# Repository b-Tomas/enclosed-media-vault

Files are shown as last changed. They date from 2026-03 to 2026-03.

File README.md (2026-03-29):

# 10" 2U Raspberry Pi 5 NAS with 6x 2.5" HDDs

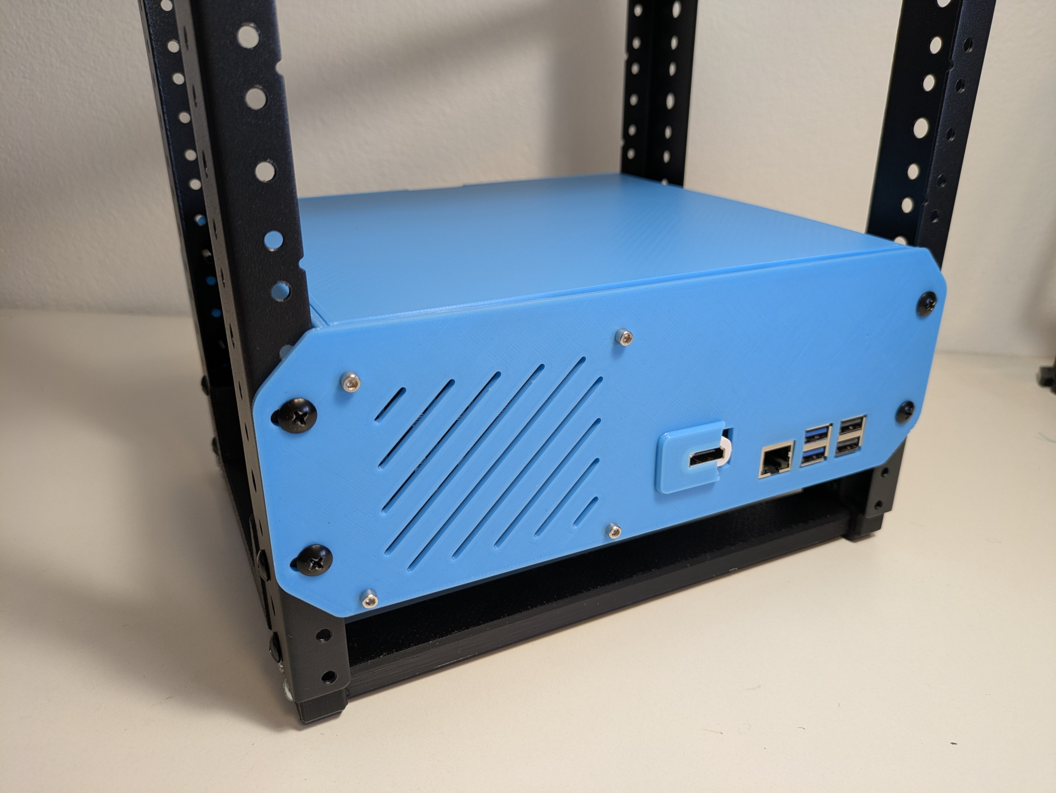
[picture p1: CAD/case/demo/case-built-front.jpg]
Assembled NAS in 10 inch rack


A 3D-printed 2U enclosure for a Raspberry Pi 5 NAS running OpenMediaVault, designed to fit a 10" mini rack. Fits up to 6x 2.5" SATA drives connected through a 6-port M.2-to-SATA adapter while booting from an NVMe SSD. Both M.2 devices run on a single PCIe lane via a switch HAT.

## Specs

| | |
| --- | --- |
| **Compute** | Raspberry Pi 5 8GB |
| **Boot drive** | 128GB M.2 2242 NVMe |
| **Storage** | 6x 1TB 2.5" SATA HDD (recycled from laptop SSD upgrades) |
| **PCIe HAT** | Geekworm X1004 dual M.2 HAT (ASM1182e PCIe switch) |
| **SATA adapter** | M.2 to SATA 6-port (ASM1166) |
| **Power** | 5V 15A PSU + SATA splitter cables |
| **OS** | OpenMediaVault |
| **Rack** | 3D-printed 10" mini rack with 6U steel rails |

## 3D-printed parts

| Component | Printables | Source |
| --- | --- | --- |
| Base chassis (2U, for 220x220mm bed) | [Printables](https://www.printables.com/model/1639121-10-2u-chassis-base-for-220x220mm-bed) | [`CAD/base-chassis/`](CAD/base-chassis/) |
| Drive box (6x 2.5") | [Printables](https://www.printables.com/model/1639132-6x-25-drive-box) | [`CAD/drives/`](CAD/drives/) |
| NAS case (2U enclosed) | <!-- TODO: upload to Printables --> | [`CAD/case/`](CAD/case/) |

All designs are FreeCAD projects with exported STLs. See [3D printing details](docs/3d-printing.md) for print notes, pending work, and third-party models used.

## Documentation

- [Bill of materials](docs/bom.md): full parts list with prices and links
- [Hardware alternatives](docs/hardware-alternatives.md): other hardware approaches explored (SATA HATs, USB, Compute Module)
- [Software](docs/software.md): OMV setup, boot fix for SATA controllers, other OSes tried
- [3D printing](docs/3d-printing.md): custom designs, STL inventory, third-party prints, reference models
- [References](docs/references.md): external links and resources

## License

[MIT](LICENSE)

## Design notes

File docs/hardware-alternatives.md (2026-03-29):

# Hardware alternatives

The Raspberry Pi 5 exposes a single PCIe 2.0 x1 lane. Connecting both an NVMe boot drive and multiple SATA storage drives from that one lane requires a PCIe switch as a workaround. This document covers the approaches considered and the one ultimately chosen.

## Chosen: Geekworm X1004 dual M.2 HAT

The final build uses the [Geekworm X1004](https://www.amazon.com/Geekworm-X1004-Peripheral-Board-Raspberry/dp/B0D3LP9KBH), a dual M.2 HAT that sits on top of the Pi 5. It has an ASM1182e PCIe switch on-board, splitting the single PCIe lane into two M.2 slots:

- **Slot 1:** 128GB 2242 NVMe SSD OEM drive bought from a shop selling scrap parts (boot drive)
- **Slot 2:** [M.2 to SATA 6-Port adapter](https://www.amazon.com/Adapter-RIITOP-Expansion-Chipset-ASM1166/dp/B0D8BCWHPT) (ASM1166 chipset) -> 6x SATA

Power is supplied by an [5V 15A PSU](https://www.amazon.com/dp/B078RT3ZPS) (I went for the biggest one, but I am not sure I would trust 15A on it), with [SATA splitter cables](https://www.amazon.com/dp/B0DFRJT3CW) distributing power to the drives (soldering required).

The original Raspberry Pi M.2 HAT (single slot, PCIe 2.0) was purchased earlier and used for a year or so when I was using a single drive on a USB adapter, but it not used in the final build.

### PCIe topology

```
$ lspci
0001:00:00.0 PCI bridge: Broadcom Inc. and subsidiaries BCM2712 PCIe Bridge (rev 21)
0001:01:00.0 PCI bridge: ASMedia Technology Inc. ASM1182e 2-Port PCIe x1 Gen2 Packet Switch
0001:02:03.0 PCI bridge: ASMedia Technology Inc. ASM1182e 2-Port PCIe x1 Gen2 Packet Switch
0001:02:07.0 PCI bridge: ASMedia Technology Inc. ASM1182e 2-Port PCIe x1 Gen2 Packet Switch
0001:03:00.0 Non-Volatile memory controller: Shenzhen Unionmemory Information System Ltd. AM620 PCIe 3.0 NVMe SSD 128GB (rev 03)
0001:04:00.0 SATA controller: ASMedia Technology Inc. ASM1166 Serial ATA Controller (rev 02)
0002:00:00.0 PCI bridge: Broadcom Inc. and subsidiaries BCM2712 PCIe Bridge (rev 21)
0002:01:00.0 Ethernet controller: Raspberry Pi Ltd RP1 PCIe 2.0 South Bridge
```

## Alternative A: FPC PCIe switch + dedicated SATA HAT

Use a separate FPC-based PCIe switch HAT to split the lane, then attach both the existing M.2 HAT and a dedicated SATA HAT.

| Component | Price | Link |
| --- | --- | --- |
| GeeekPi RPi5 B12 Dual FPC PCIe HAT | USD 24.99 | [Amazon](https://www.amazon.com/GeeekPi-HAT-Raspberry-B12-Interface/dp/B0D2VTL9G5) |
| Radxa Penta SATA HAT | USD 79.99 | [Amazon](https://www.amazon.com/Radxa-Penta-SATA-HAT-Raspberry/dp/B0DX1HQWB2) |
| Geekworm X1009 PCIe to 5-port SATA HAT | USD 60.00 | [AliExpress](https://es.aliexpress.com/item/1005009068994117.html) |
| Waveshare Pi5 Connector Adapter C | USD 10.00 | [Waveshare](https://www.waveshare.com/pi5-connector-adapter-c.htm) |

**Downsides:** The Penta SATA HAT is expensive and hard to source. The X1009 is more affordable and includes 12V DC input (also powers the Pi; do NOT also power via USB-C), but still requires the FPC switch HAT on top.

## Alternative B: Dual M.2 HAT + M.2-to-SATA adapter

This is the approach that was ultimately chosen (see above). For reference, cheaper alternatives were also considered:

| Component | Price | Link |
| --- | --- | --- |
| Geekworm X1004 Dual M.2 HAT (supports boot) | USD 29.90 | [Amazon](https://www.amazon.com/Geekworm-X1004-Peripheral-Board-Raspberry/dp/B0D3LP9KBH) |
| Cheaper dual M.2 HAT (likely no boot support) | USD 18.59 | [AliExpress](https://es.aliexpress.com/item/1005007485668597.html) |
| Another dual M.2 option | USD 25.99 | [AliExpress](https://es.aliexpress.com/item/1005006533152444.html) |
| RIITOP M.2 to SATA 6-Port (ASM1166) | USD 39.99 | [Amazon](https://www.amazon.com/Adapter-RIITOP-Expansion-Chipset-ASM1166/dp/B0D8BCWHPT)  |
| Cheaper M.2 to SATA adapter | -- | [AliExpress](https://es.aliexpress.com/item/1005010015675089.html) |

## Alternative C: USB 3.0 to SATA

The simplest approach. No PCIe splitting needed. Just plug USB-to-SATA adapters into the Pi's USB 3.0 ports.

| Component | Price | Link |
| --- | --- | --- |
| USB 3.0 to 2.5" SATA adapter | ARS 23,200 (x2) | [MercadoLibre](https://www.mercadolibre.com.ar/cable-sata-usb-30-adaptador-conversor-disco-hdd-ssd-25-color-negro/p/MLA48683516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) |

**Trade-off:** Simple and cheap, but bandwidth-limited by USB 3.0 and no hardware RAID support. Two adapters were purchased early on during experimentation. Originally used with a single WD Elements 2TB drive; considered buying more but moved to the PCIe SATA approach instead.

**Notes:**

- I tried connecting a couple of USB drives at once to move files around, and the controller evetually died
- OMV does not support creeating RAID or ZFS filesystems over USB drives. I experimented with a RAID1 setup with two 1TB drives that performed fine, but I had to create it via CLI.

## Alternative D: Compute Module 5

Use a CM5 with a carrier board that has native SATA ports and an NVMe slot, eliminating the need for PCIe switching entirely.

| Component | Price | Link |
| --- | --- | --- |
| Exaviz Interceptor Carrier Board v2.0 | ~USD 80 | [Exaviz](https://www.exaviz.com/product-page/interceptor-carrier-board-v2-0) |
| Radxa Taco IO Board | -- | [Radxa](https://radxa.com/products/io-board/taco/#techspec) |

**Blocker:** The CM5 is hard to obtain, and can get expensive.

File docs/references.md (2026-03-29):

# References

## Inspiration

- [Project Mini Rack](https://www.jeffgeerling.com/blog/2024/project-mini-rack-compact-and-portable-homelabs) -- Jeff Geerling's compact homelab project
- [geerlingguy/mini-rack](https://github.com/geerlingguy/mini-rack) -- GitHub repo with builds and documentation

## Pi 5 PCIe

- [Pi PCIe HAT database](https://pipci.jeffgeerling.com/hats) -- compatibility list for PCIe HATs
- [Testing PCIe on Raspberry Pi 5](https://www.jeffgeerling.com/blog/2023/testing-pcie-on-raspberry-pi-5)

## Troubleshooting

- [AHCI boot fix discussion](https://forums.raspberrypi.com/viewtopic.php?t=363682#p2195153) -- Raspberry Pi forums
- [raspberrypi/linux#4848](https://github.com/raspberrypi/linux/issues/4848) -- related kernel issue

## NixOS on Pi 5

- [NixOS Wiki: Raspberry Pi 5](https://wiki.nixos.org/wiki/NixOS_on_ARM/Raspberry_Pi_5)
- [pdg137/pi5-nixos-setup](https://github.com/pdg137/pi5-nixos-setup)
- [nvmd/nixos-raspberrypi](https://github.com/nvmd/nixos-raspberrypi)

## Compute Module research

- [ChatGPT deep research: CM5 carrier boards](https://chatgpt.com/share/68ed2ff8-9aa0-8009-b2a6-e3ce2d3727fe)
- [Exaviz Interceptor Carrier Board v2.0](https://www.exaviz.com/product-page/interceptor-carrier-board-v2-0)
- [Radxa Taco IO Board](https://radxa.com/products/io-board/taco/#techspec)

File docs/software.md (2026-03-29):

# Software

## Current setup: OpenMediaVault

The NAS runs [OpenMediaVault](https://www.openmediavault.org/) on a Raspberry Pi 5, booting from the NVMe SSD behind the Geekworm X1004's PCIe switch.

<!-- TODO: OMV version, share configuration, ZFS setup, apps -->

## SATA controller boot fix

With the ASM1166 SATA controller and hard drives connected, the Pi would crash at boot with:

```
AHCI controller unavailable!
```

The fix is included in recent kernels. Add to `/boot/firmware/config.txt`:

```ini
# Required for SATA controllers behind PCIe switches.
# See: https://github.com/raspberrypi/linux/issues/4848
#      https://forums.raspberrypi.com/viewtopic.php?t=363682#p2195153
dtoverlay=pciex1-compat-pi5,no-mip
dtoverlay=pcie-32bit-dma-pi5
```

## Other OSes explored

### Umbrel

Tried early on. Nice UI, but too limited for NAS use. Lacks proper storage management, RAID, and file sharing configuration.

### NixOS

No official support for RPi 5. I managed to install and boot it but did not invest too much time in setting it up. Built the image on a Pop!\_OS-based x86 VM with Nix installed.

Resources:

- [NixOS on ARM: Raspberry Pi 5](https://wiki.nixos.org/wiki/NixOS_on_ARM/Raspberry_Pi_5)
- [pdg137/pi5-nixos-setup](https://github.com/pdg137/pi5-nixos-setup) (deployment example)
- [nvmd/nixos-raspberrypi](https://github.com/nvmd/nixos-raspberrypi) (upstream reference)

<!-- TODO: NixOS configuration details if/when completed -->

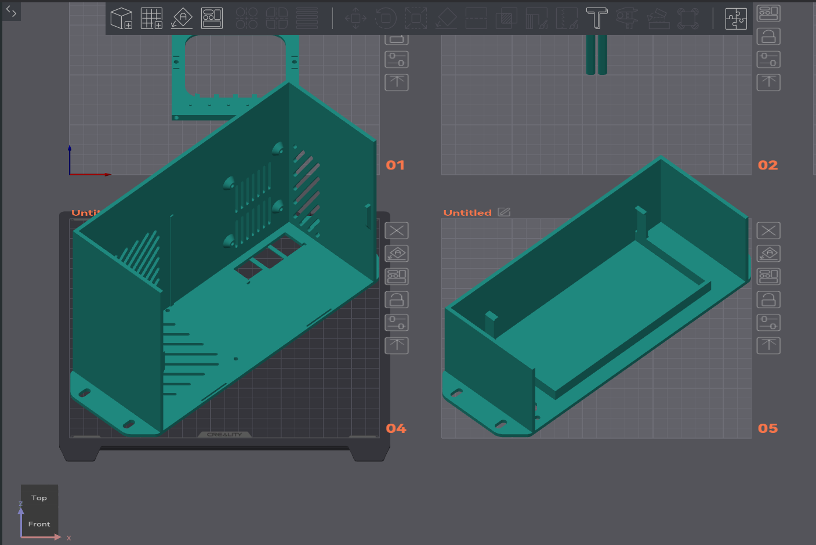
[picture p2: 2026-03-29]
CAD/base-chassis/demo/base-examples-slicer.png

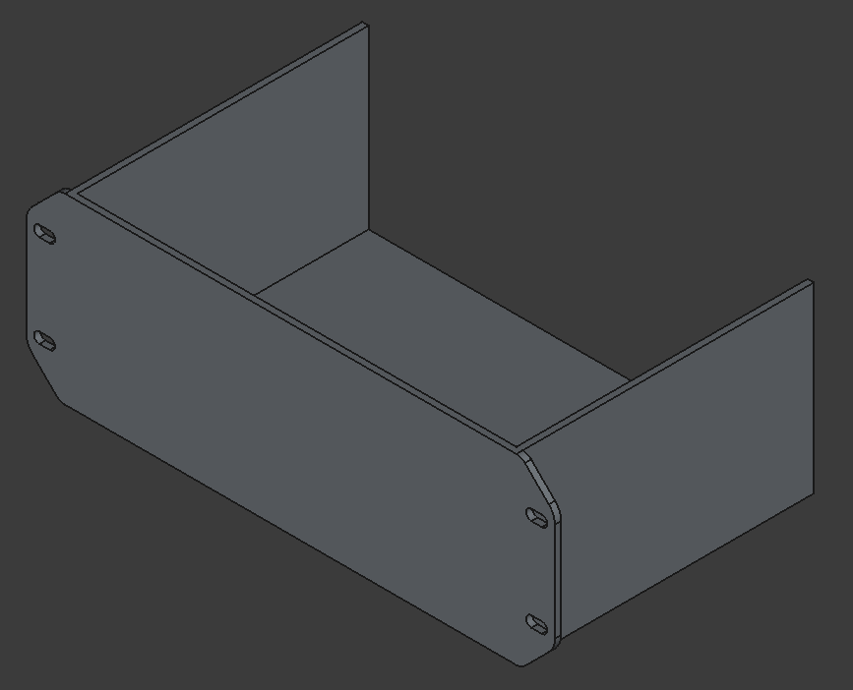
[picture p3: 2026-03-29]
CAD/base-chassis/demo/base-freecad.png

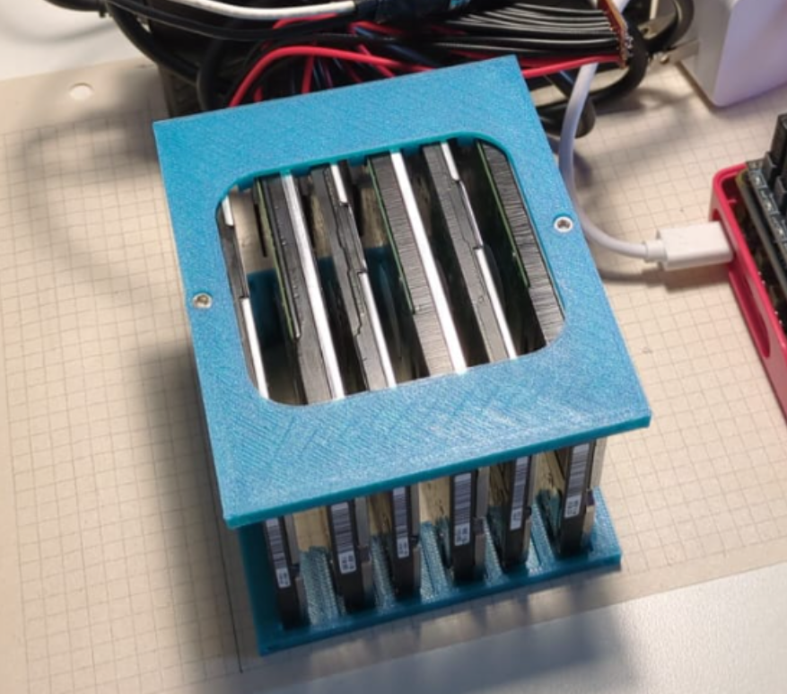
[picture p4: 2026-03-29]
CAD/drives/demo/drives-built.png

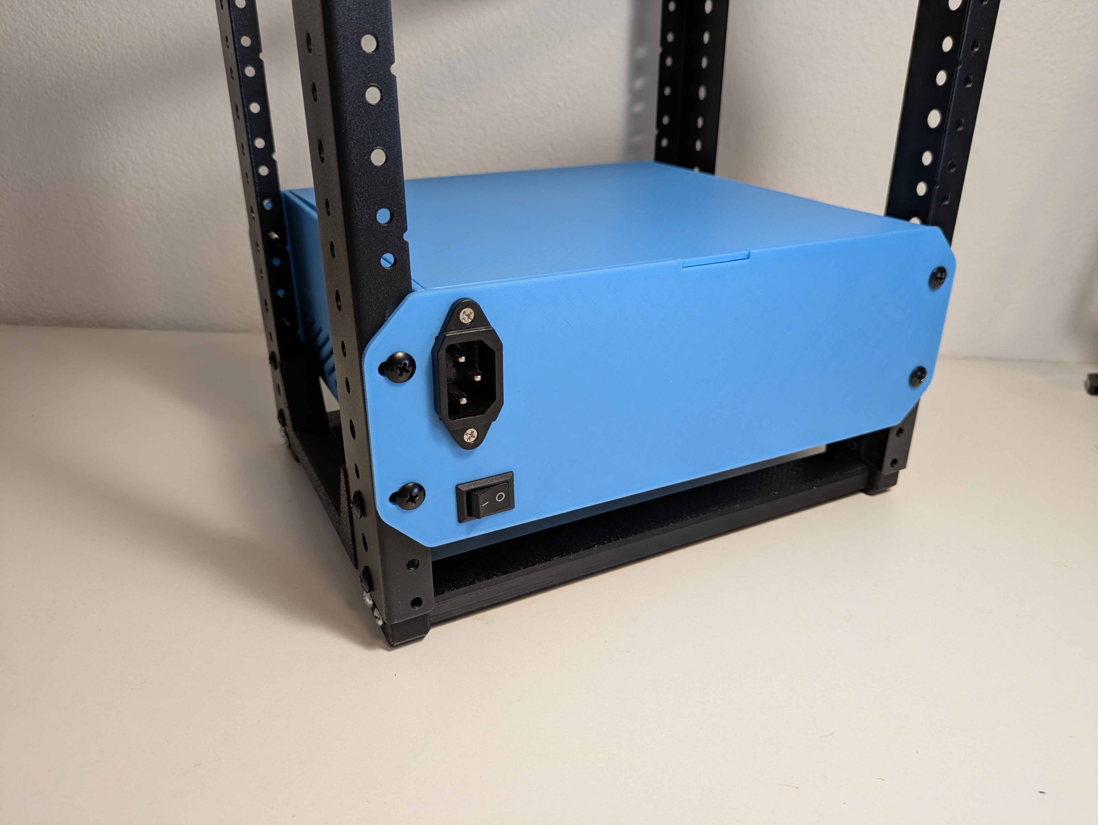
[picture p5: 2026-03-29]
CAD/case/demo/case-built-back.jpg

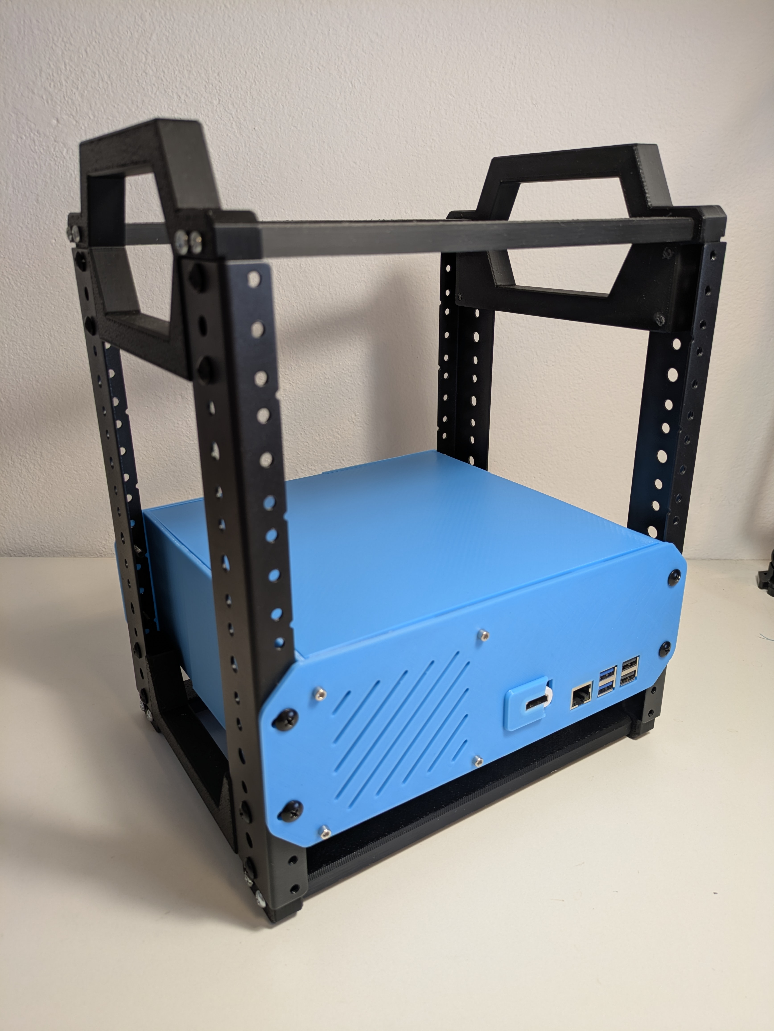
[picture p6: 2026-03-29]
CAD/case/demo/rack.jpg

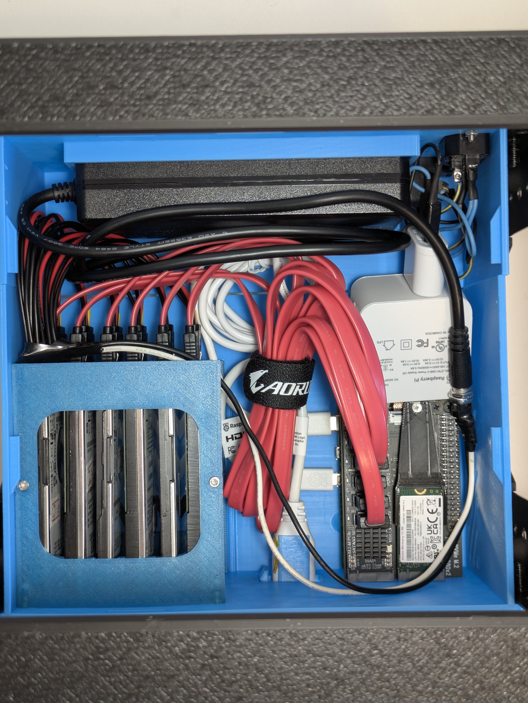
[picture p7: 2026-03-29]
CAD/case/demo/case-internals.jpg

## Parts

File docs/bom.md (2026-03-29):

# Bill of Materials

<!-- TODO: add missing prices, dates and links https://github.com/b-Tomas/enclosed-media-vault/issues/5 -->
<!-- TODO: add convertions to USD adjusted to the purchased date, and total costs in USD https://github.com/b-Tomas/enclosed-media-vault/issues/5 -->

## Final build

Items currently in use in the NAS.

### Computing

| Item | Qty | Price | Date | Link |
| --- | --- | --- | --- | --- |
| Raspberry Pi 5 8GB | 1 | $0 | ~Feb 2024 | Local store, Mountain View |
| RPi 5 active cooler | 1 | ARS 14,589 | Jul 2025  | [MercadoLibre](https://articulo.mercadolibre.com.ar/MLA-1941204168-cooler-activo-raspberry-compatible-pi-5-fan-radiador-pwm-stw-_JM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) |
| Geekworm X1004 PCIe to Dual M.2 HAT | 1 | USD 29.90 | -- | [Amazon](https://www.amazon.com/Geekworm-X1004-Peripheral-Board-Raspberry/dp/B0D3LP9KBH) |
| M.2 to SATA 3.0 6-Port Adapter (ASM1166) | 1 | USD 39.99 | -- | [Amazon](https://www.amazon.com/Adapter-RIITOP-Expansion-Chipset-ASM1166/dp/B0D8BCWHPT) |
| SSD M.2 128GB 2242 NVMe (OEM salvaged part) | 1 | ARS 11,532.50 | Jul 2025  | [MercadoLibre](https://articulo.mercadolibre.com.ar/MLA-1923490540-ssd-m2-128gb-disco-duro-solido-2242-nvme-union-memory-ymtc-_JM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) |

### Storage

| Item | Qty | Price | Date | Link |
| --- | --- | --- | --- | --- |
| 2.5" 1TB HDD (recycled from laptop SSD upgrades) | 6 | ARS 140,000 (~USD 100) | Nov 2025 | Local seller (FB Marketplace) |

### Power and cabling

| Item | Qty | Price | Date | Link |
| --- | --- | --- | ---- | --- |
| 5V 15A AC to DC Power Supply | 1 | -- | -- | [Amazon](https://www.amazon.com/dp/B078RT3ZPS) |
| SATA Power Splitter Cable (4pcs, 15-pin M to dual F) | 1 | -- | -- | [Amazon](https://www.amazon.com/dp/B0DFRJT3CW) |
| RPi Micro-HDMI to HDMI A/F cable | 1 | <!-- TODO: price --> | -- | <!-- TODO: MercadoLibre link --> |

### Hardware

| Item | Qty | Price | Date | Link |
| --- | --- | --- | --- | --- |
| M3 Threaded Inserts Set (360pcs) + 60W Soldering Iron | 1 | USD 22.99 | Sep 2025 | [Amazon](https://www.amazon.com/dp/B0F9WDPG6S) |
| 6U Steel Rack Rails Kit (2pcs) | 2 | USD 23.98 total | Sep 2025 | [Amazon](https://www.amazon.com/dp/B08RYR49RZ) |

## Other purchases

Items bought during the project but not part of the final build.

| Item | Qty | Price | Date | Link | Notes |
| --- | --- | --- | --- | --- | --- |
| RPi official case | 1 | -- | -- | Local store, Mountain View | Replaced by custom 3D-printed case |
| 64GB Kingston MicroSD | 2 | $0 | -- | Local store, Mountain View | Used before NVMe boot setup |
| RPi M.2 HAT PCIe 2.0 (single slot) | 1 | ARS 21,956 | Jul 2025 | [MercadoLibre](https://www.mercadolibre.com.ar/placa-expansion-raspberry-pi-m2-hat-pi-5-pcie-20-interfaz/p/MLA44954011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) | Used for ~1 year with single-drive setup, replaced by X1004 |
| USB 3.0 to 2.5" SATA adapter | 2 | ARS 23,200 total | Oct 2025 | [MercadoLibre](https://www.mercadolibre.com.ar/cable-sata-usb-30-adaptador-conversor-disco-hdd-ssd-25-color-negro/p/MLA48683516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) | From earlier USB approach |
| WD Elements 2TB 2.5" HDD | 1 | -- | -- | A gift. Alternative link: [Amazon](https://www.amazon.com/gp/product/B06W55K9N6) | Used in single-drive setup before switching to 6x 1TB |

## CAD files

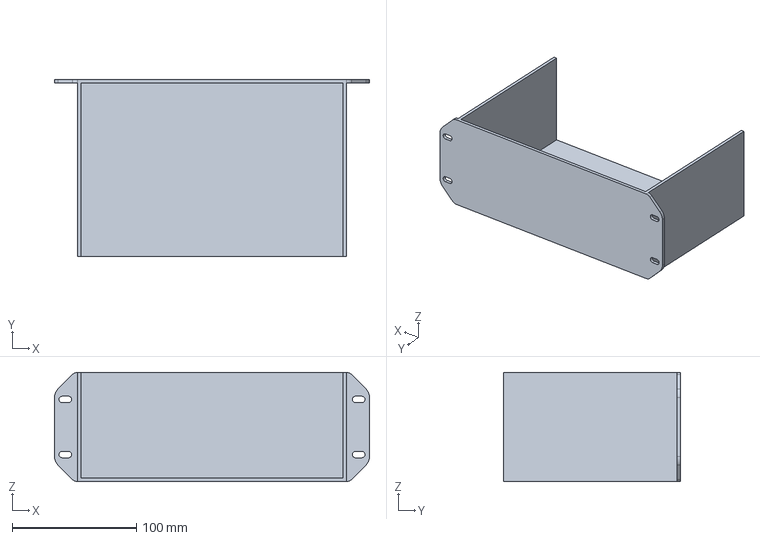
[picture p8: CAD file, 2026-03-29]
CAD/base-chassis/10-inch-2U-chassis-base.FCStd
254.0 x 143.0 x 87.9 mm

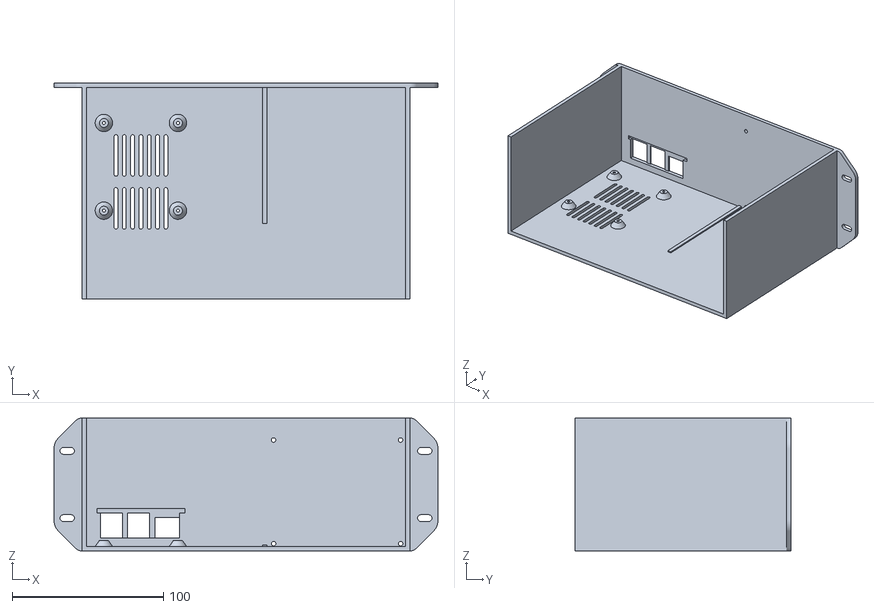
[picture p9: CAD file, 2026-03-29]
CAD/case/stl/case-Body.stl
254.0 x 143.0 x 87.9

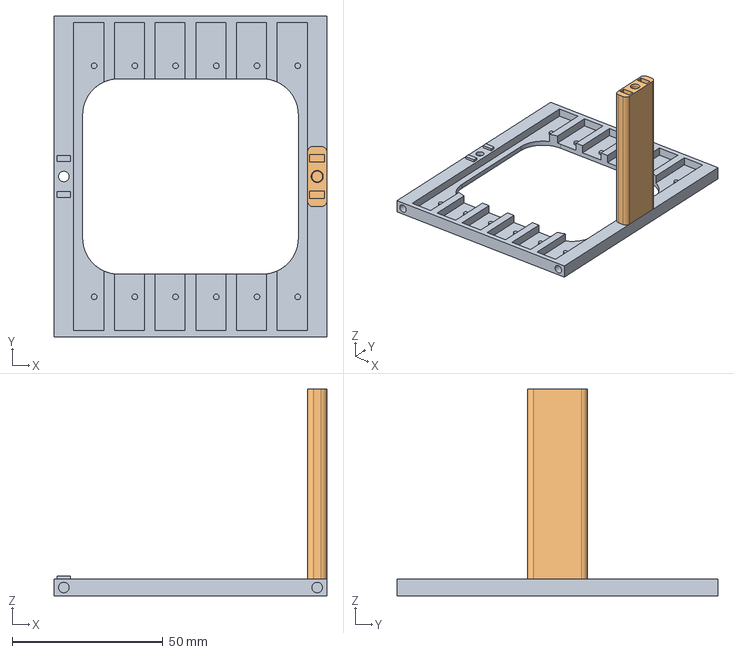
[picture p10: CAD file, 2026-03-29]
CAD/drives/drives.FCStd
90.5 x 106.4 x 68.5 mm
rib

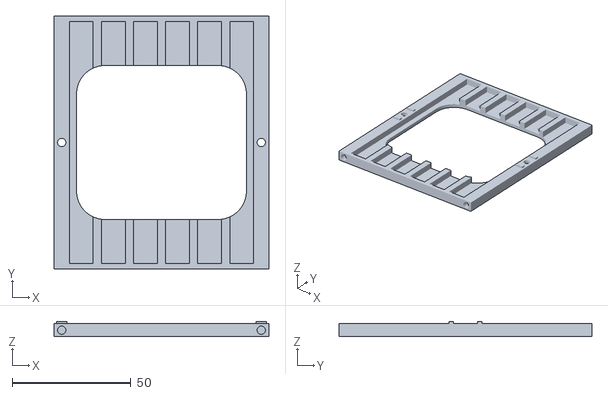
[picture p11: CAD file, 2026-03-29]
CAD/drives/stl/drives-base.stl
90.5 x 106.4 x 6.50

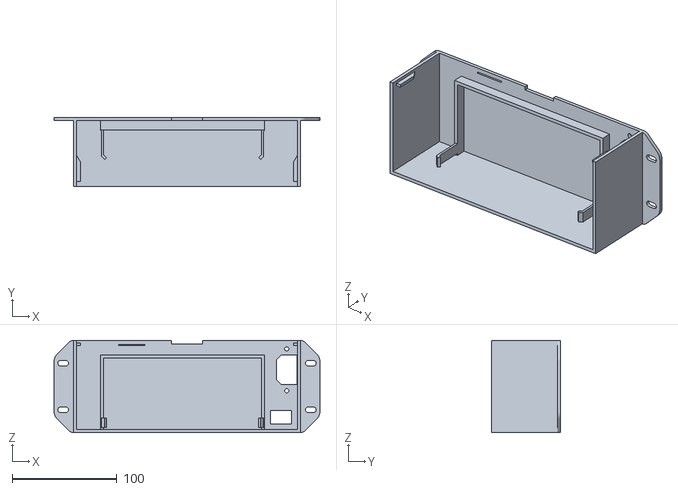
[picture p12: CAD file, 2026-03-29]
CAD/case/stl/case-Back.stl
254.0 x 66.0 x 87.9

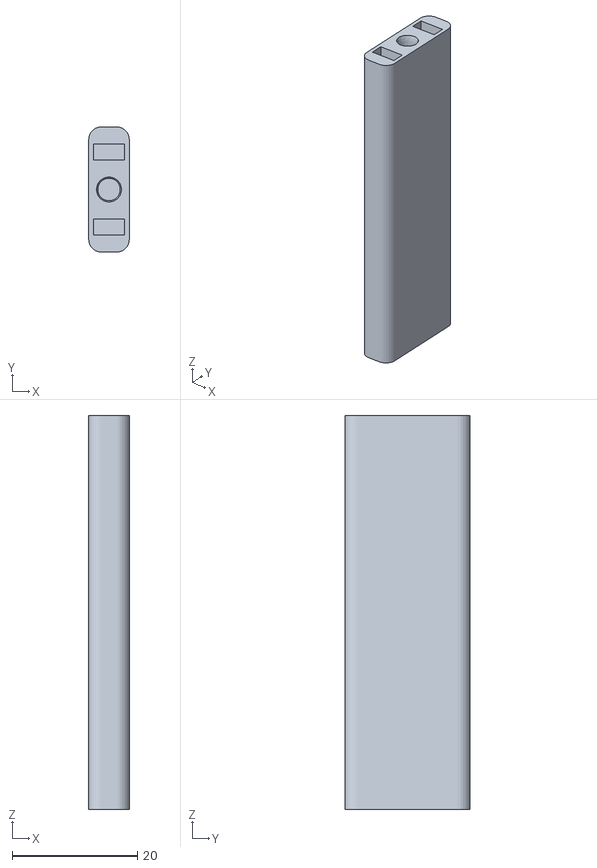
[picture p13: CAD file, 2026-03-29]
CAD/drives/stl/drives-rib.stl
6.50 x 20.0 x 63.0

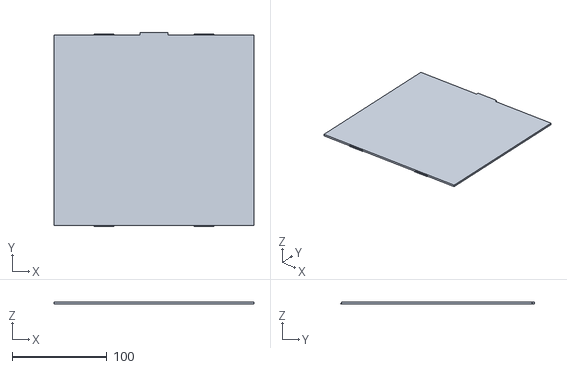
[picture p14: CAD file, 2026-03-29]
CAD/case/stl/case-Cover.stl
211.0 x 205.0 x 2.30

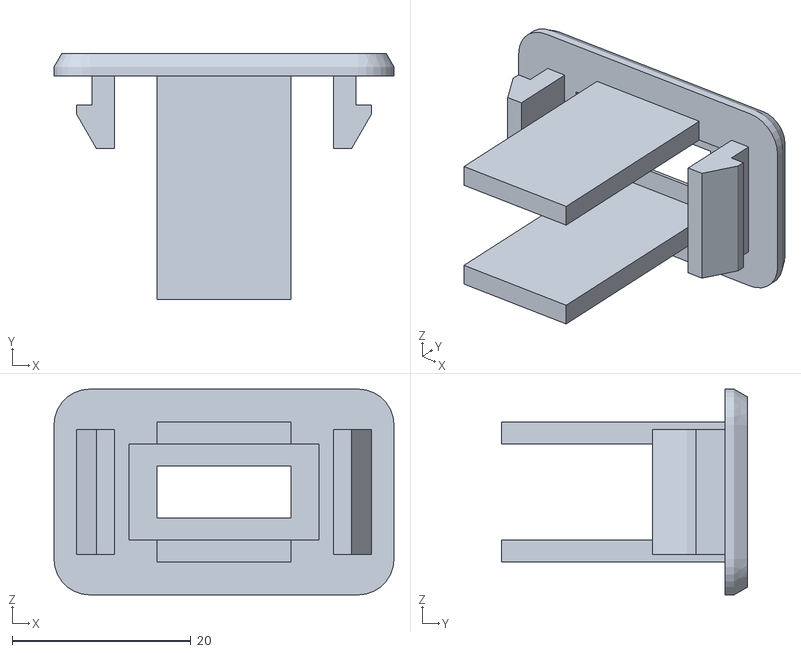
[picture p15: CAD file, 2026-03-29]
CAD/case/stl/case-HDMI.stl
38.0 x 27.5 x 23.0

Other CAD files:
CAD/base-chassis/stl/10-inch-2U-chassis-base-Base.stl
CAD/case/case.FCStd
CAD/case/stl/case-Front.stl

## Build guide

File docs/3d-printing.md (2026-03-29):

# 3D printing

## Custom designs

All source files are FreeCAD projects. STLs are included for direct slicing.

| Component | Description | Printables | Source |
| --- | --- | --- | --- |
| Base chassis | 10" 2U open chassis, designed for 220x220mm print beds. U-shaped tray with rack ears and M3 threaded insert holes for standard 10" rails. | [Printables](https://www.printables.com/model/1639121-10-2u-chassis-base-for-220x220mm-bed) | [`CAD/base-chassis/`](../CAD/base-chassis/) |
| Drive box | Holds 6x 2.5" drives vertically. Consists of a base tray and separating ribs that slot between drives. Ventilation slots on top. | [Printables](https://www.printables.com/model/1639132-6x-25-drive-box) | [`CAD/drives/`](../CAD/drives/) |
| NAS case | 2U enclosed case with 5 pieces: body, front panel, back panel, cover, and HDMI cutout. Front panel has USB and HDMI passthrough; back panel has an IEC C14 power inlet cutout. Houses the drive box, Pi, and all cabling. | <!-- TODO: upload to Printables --> | [`CAD/case/`](../CAD/case/) |

### STL files

**Base chassis:** `10-inch-2U-chassis-base-Base.stl`

**Drive box:** `drives-base.stl`, `drives-rib.stl`

**NAS case:** `case-Body.stl`, `case-Front.stl`, `case-Back.stl`, `case-Cover.stl`, `case-HDMI.stl`

### Pending CAD work

See the issues page.

## Third-party prints used

- [Mini Rack 10" server rack](https://www.printables.com/model/1210194) by StreelyDan. The rack frame itself, which happened to be compatible with the 6U rails I bought
- [M.2 2230/2242/2260 to 2280 adapter](https://www.printables.com/model/217264-223022422260-to-2280-m2-adapter-ssd) by nzalog

## Other references explored

Designs that were reviewed but not printed. Kept here for future reference.

**Cases:**

- [10" mini rack with solid side walls](https://www.printables.com/model/1261430)

**Ventilation:**

- [10" rack vent panels](https://makerworld.com/en/models/1192269)

**Drive bays (3.5" -- not used, but useful reference):**

- [1U 2x 3.5" HDD mount, no hotswap](https://www.printables.com/model/1320021)
- [1U 2x 3.5" HDD, hotswap](https://www.printables.com/model/1290788)
- [3U 8-drive bay](https://www.thingiverse.com/thing:6930930)
- [2U 4-drive mount with fan support](https://www.printables.com/model/1418516)
